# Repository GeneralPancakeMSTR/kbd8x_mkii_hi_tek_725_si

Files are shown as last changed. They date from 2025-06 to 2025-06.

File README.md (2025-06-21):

# KBD8XMKII "Space Invaders" TKL
PCB For NMB Hi-Tek Series 725 "Space Invaders" Switches and KBDFans KBD8XMKII TKL Keyboard. 

It's for this keyboard:


<center><p>My personal KBD8XMKII Keyboard</p></center>

Probably *literally* that keyboard, which is mine (I can only imagine the Venn diagram of Space Invaders collectors and KBD8XMKII owners is two distant circles). It's a [KBDFans](https://kbdfans.com/) KBD8XMKII, which isn't made anymore. I don't even think you can find it on their website, which seems to just [redirect you to their MKIII](https://kbdfans.com/collections/kbd8x-mkii-1) when you go looking for it. 

Anyway, the [KBD8XMKII](https://ai03.com/projects/kbd8x-mkii/) (scroll to the bottom for the PCB and plate files) was a keyboard designed by the renowned ai03, who graciously open-sourced the project, which helped make this one possible by derivation. Thanks! 

This PCB is specifically designed for use with [NMB Hi-Tek Series 725 "Space Invaders" switches](https://telcontar.net/KBK/Hi-Tek/Series_725) (this is the first link a search came up with), which also aren't made anymore. As you can see, this project has truly reached maximum usefulness. 

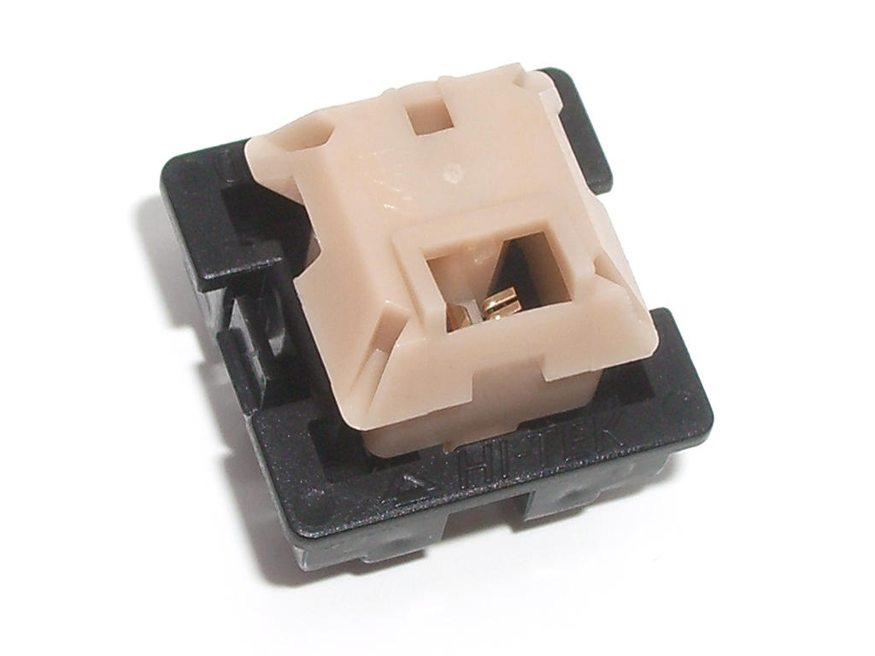
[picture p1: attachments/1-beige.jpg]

<center><p>A Beige (tactile) NMB Hi-Tek Series 725 "Space Invaders" Switch </p></center>

I've been a mechanical keyboard hobbyist for a while now (a decade?), and I've wanted to make my own keyboard about from the beginning. The hangup for me has always been the PCB, so instead of trying to make an expensive CNC case and (hopefully) figuring out the PCB later, I finally decided that to push that particular project forward I would learn the PCB side of things and then revisit the case aspect with some new knowledge and experience under my belt. 

## Reference Photos 
- PCB Top 
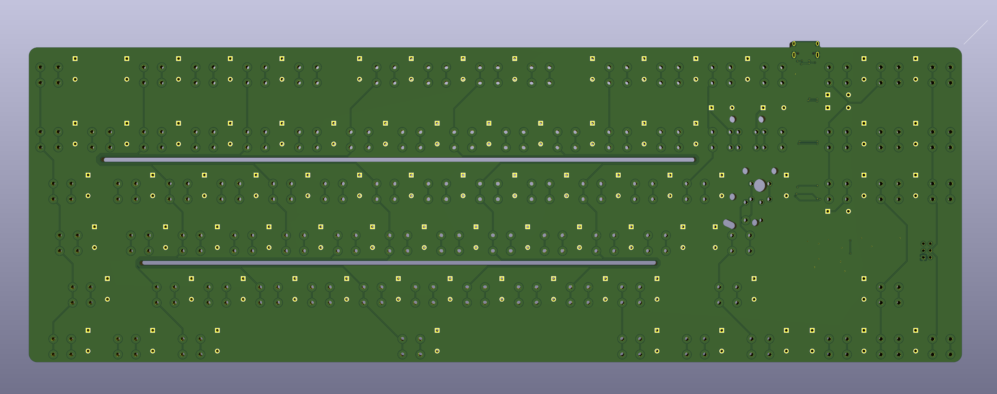
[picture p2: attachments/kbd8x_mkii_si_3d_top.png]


- PCB Bottom
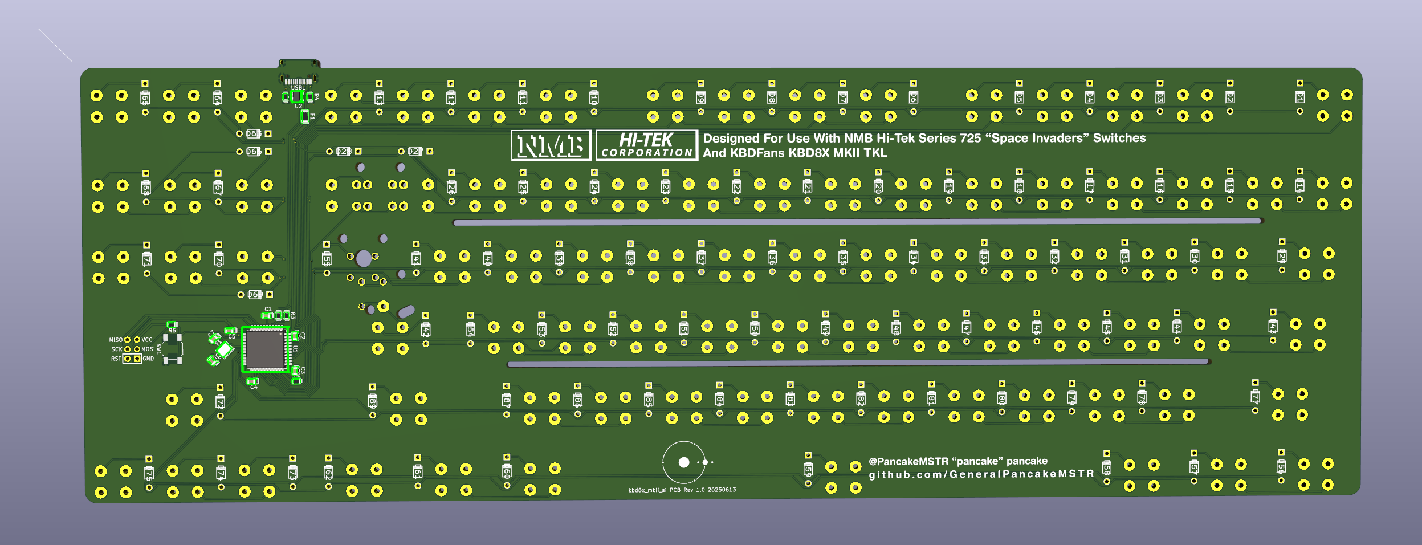
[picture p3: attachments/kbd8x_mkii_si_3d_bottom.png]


- Schematic (Logic)
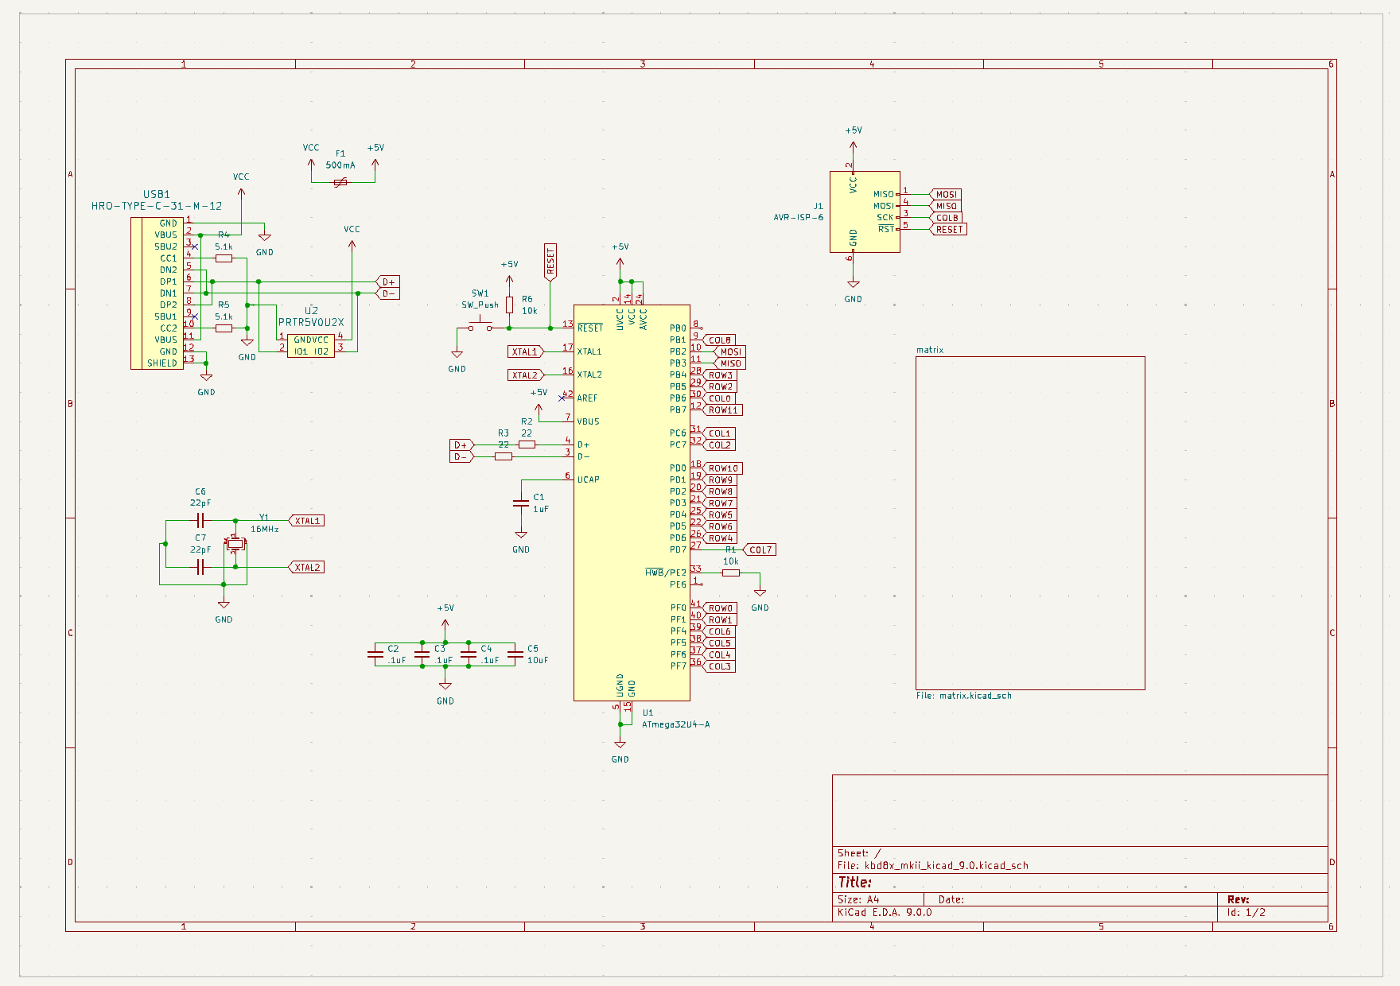
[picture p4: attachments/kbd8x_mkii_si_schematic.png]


- Schematic (Matrix)
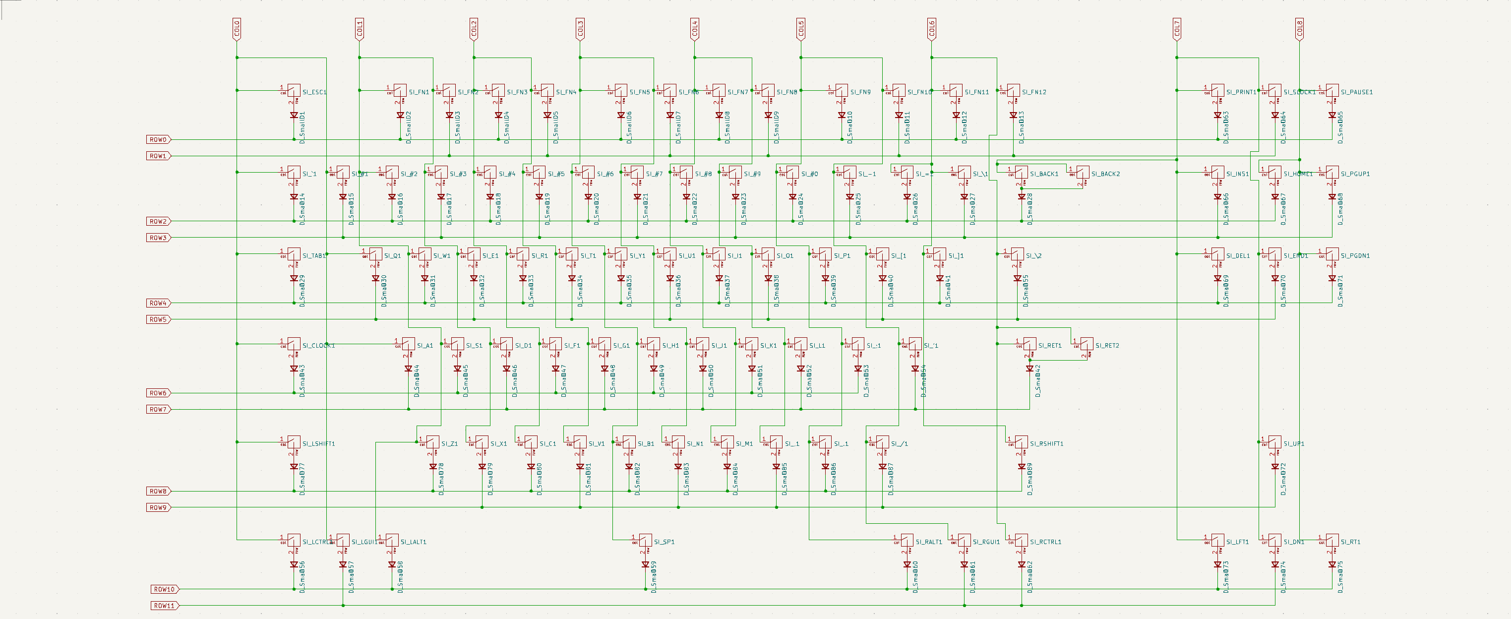
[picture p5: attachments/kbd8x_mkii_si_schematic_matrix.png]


- Layout/PCB 
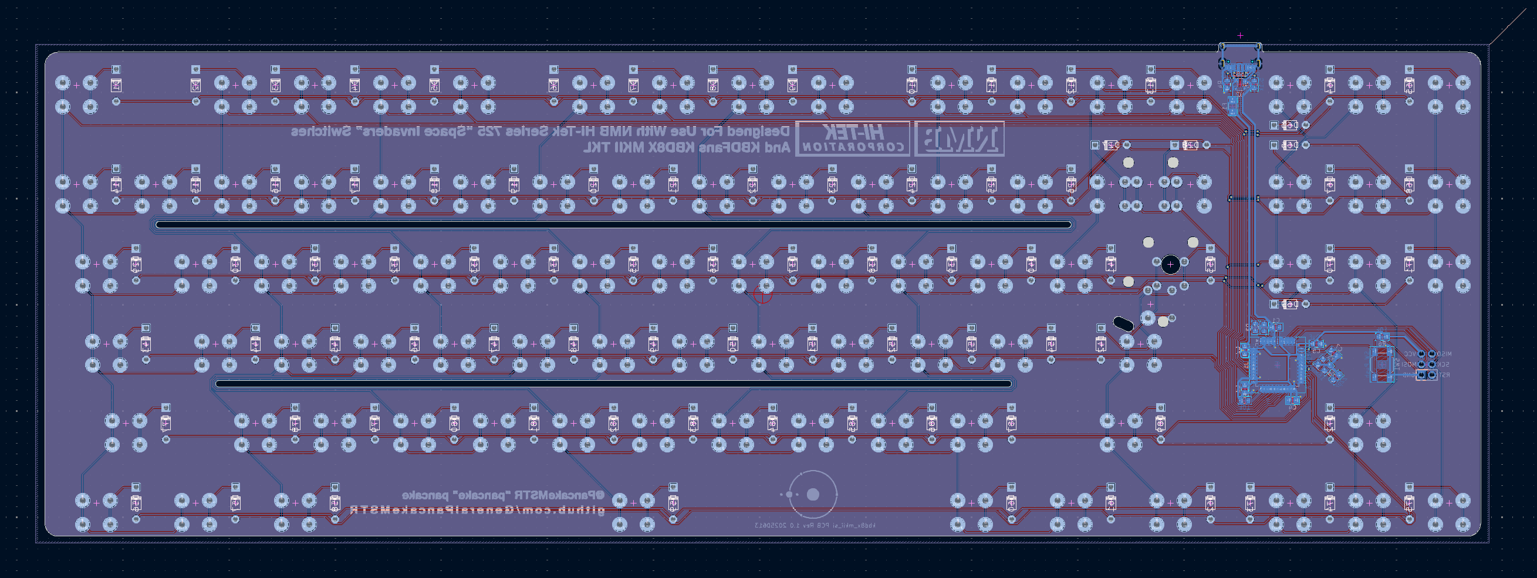
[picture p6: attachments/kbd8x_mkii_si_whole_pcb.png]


- Layout/PCB (MCU + USB)
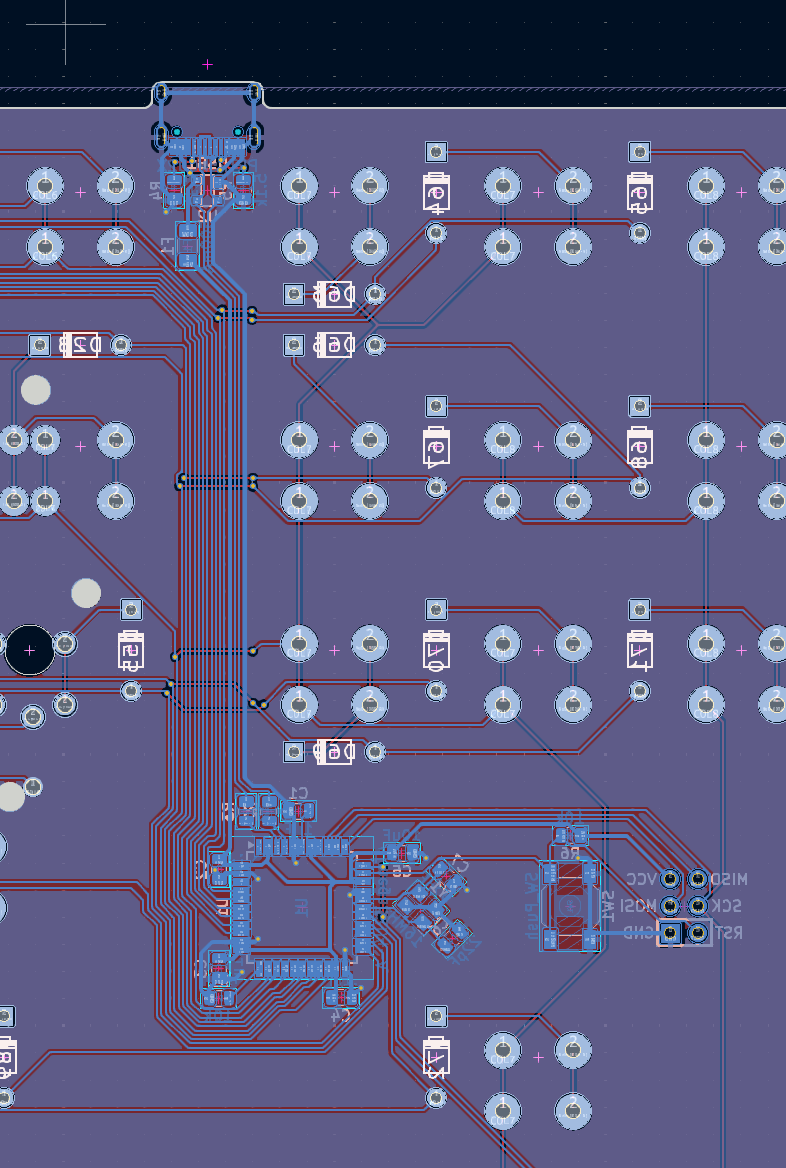
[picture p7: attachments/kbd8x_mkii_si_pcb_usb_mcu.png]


- Layout/PCB (USB)
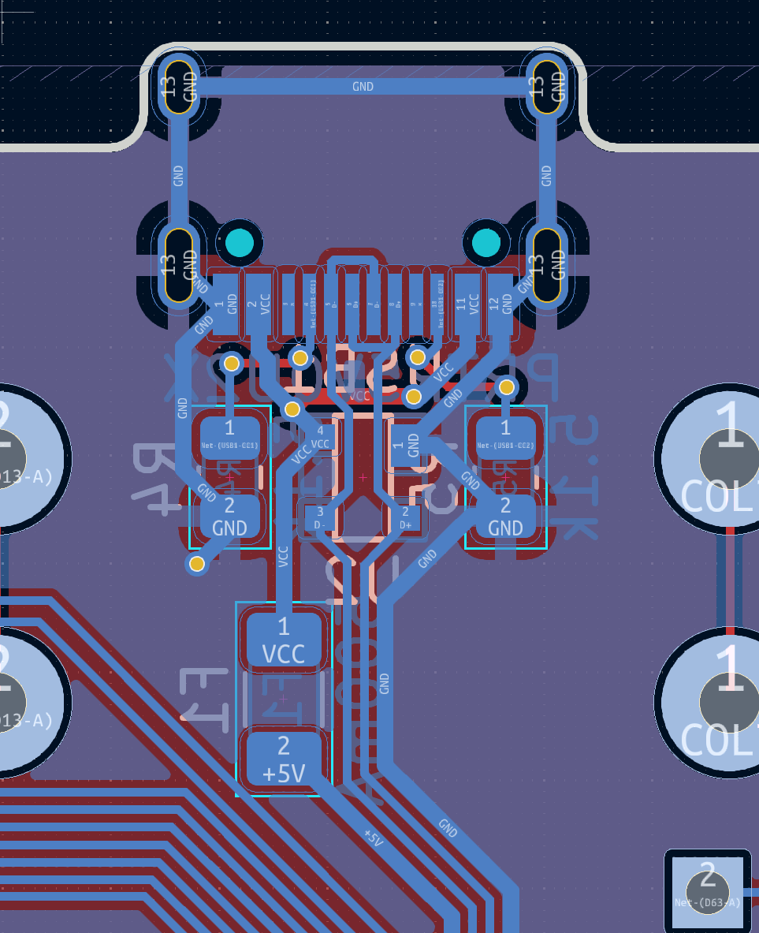
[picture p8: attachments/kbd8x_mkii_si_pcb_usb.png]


- Layout/PCB (MCU)
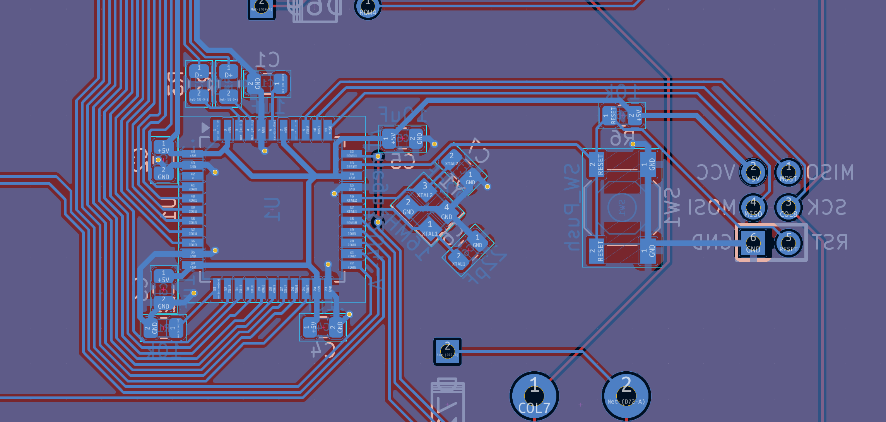
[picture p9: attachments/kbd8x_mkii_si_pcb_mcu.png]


## Notes 
- If shims are needed, these could be an option: [Clipped Washer 18-8 Stainless Steel, for M2 Screw Size, 2.200 mm ID, 4.500 mm OD](https://www.mcmaster.com/96025A268/)

- **IMPORTANT**: The placement of the Atmega32u4 in JLCPCB's PCBA may be wrong and need to be rotated. If you are getting this PCB made with PCBA, **quadruple check the placement of all of the components.**

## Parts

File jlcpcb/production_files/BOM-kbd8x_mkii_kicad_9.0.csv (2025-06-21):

Comment | Designator | Footprint | LCSC | Quantity
16MHz | Y1 | Crystal_SMD_3225-4Pin_3.2x2.5mm | C13738 | 1
10uF | C5 | C_0805_2012Metric | C15850 | 1
HRO-TYPE-C-31-M-12 | USB1 | HRO-TYPE-C-31-M-12 | C165948 | 1
10k | R1,R6 | R_0805_2012Metric | C17414 | 2
22 | R2,R3 | R_0805_2012Metric | C17561 | 2
22pF | C6,C7 | C_0805_2012Metric | C1804 | 2
ATmega32U4-A | U1 | TQFP-44_10x10mm_P0.8mm | C2052746 | 1
5.1k | R4,R5 | R_0805_2012Metric | C27834 | 2
1uF | C1 | C_0805_2012Metric | C28323 | 1

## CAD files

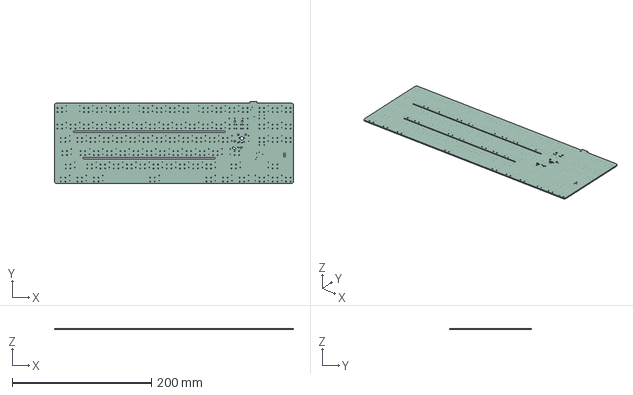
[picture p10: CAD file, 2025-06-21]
kbd8x_mkii_kicad_9.0.step
343.7 x 118.3 x 1.51 mm

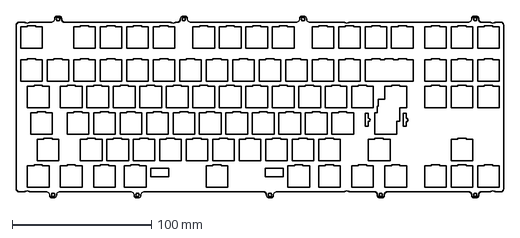
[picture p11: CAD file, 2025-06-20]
kbd8x_mkii_hi_tek_725_si_plate.dxf
350.6 x 130.7 mm

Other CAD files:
models/kbd8x_mkii_adjusted_origin.step
models/kbd8x_mkii_kicad_9.0.step

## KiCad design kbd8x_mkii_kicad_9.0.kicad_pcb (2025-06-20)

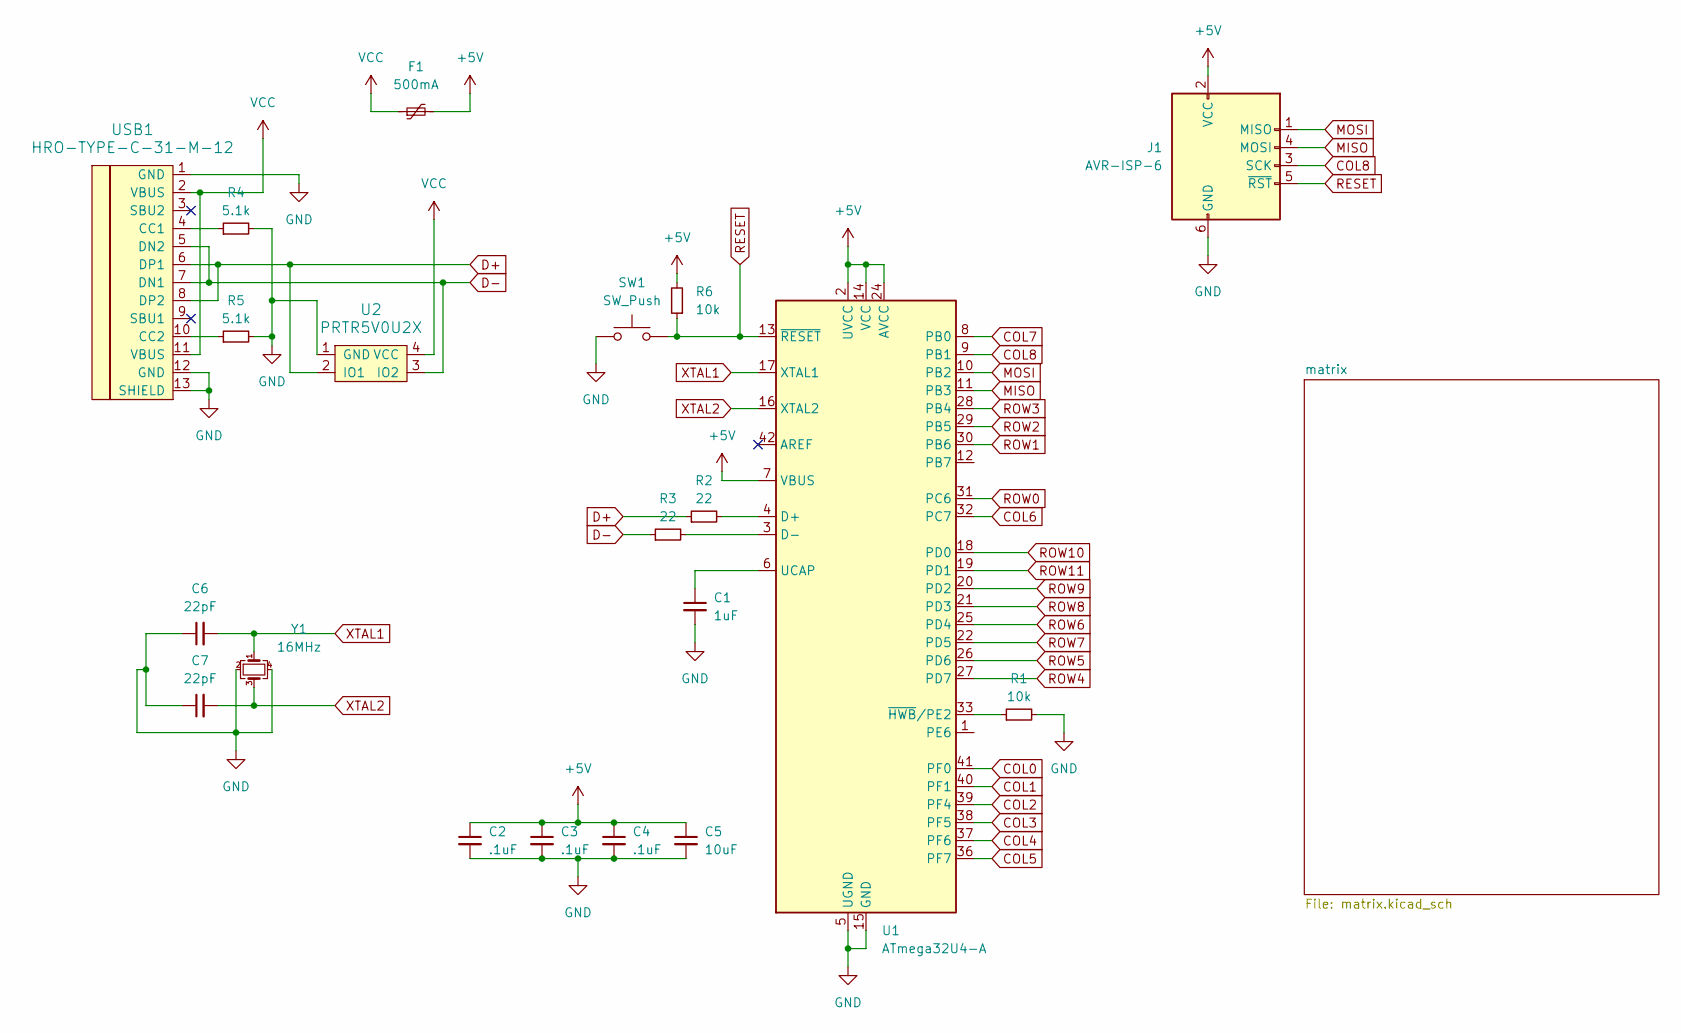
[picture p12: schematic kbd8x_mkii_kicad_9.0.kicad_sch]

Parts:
C1: 1uF; C_0805_2012Metric
C2, C3, C4: .1uF; C_0805_2012Metric
C5: 10uF; C_0805_2012Metric
C6, C7: 22pF; C_0805_2012Metric
F1: 500mA; Fuse_1206_3216Metric
J1: AVR-ISP-6; Reset_Pretty-Mask
R1, R6: 10k; R_0805_2012Metric
R2, R3: 22; R_0805_2012Metric
R4, R5: 5.1k; R_0805_2012Metric
SW1: SW_Push; SW_SPST_SKQG_WithStem
U1: ATmega32U4-A; TQFP-44_10x10mm_P0.8mm
U2: PRTR5V0U2X; SOT143B
USB1: HRO-TYPE-C-31-M-12
Y1: 16MHz; Crystal_SMD_3225-4Pin_3.2x2.5mm

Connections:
+5V: C2.1, C3.1, C4.1, C5.1, F1.2, J1.2 (VCC), R6.2, U1.2 (UVCC), U1.7 (VBUS), U1.14 (VCC), U1.24 (AVCC), U1.34 (VCC), U1.44 (AVCC)
COL0: U1.41 (PF0); also elsewhere on the board
COL1: U1.40 (PF1); also elsewhere on the board
COL2: U1.39 (PF4); also elsewhere on the board
COL3: U1.38 (PF5); also elsewhere on the board
COL4: U1.37 (PF6); also elsewhere on the board
COL5: U1.36 (PF7); also elsewhere on the board
COL6: U1.32 (PC7); also elsewhere on the board
COL7: U1.8 (PB0); also elsewhere on the board
COL8: J1.3 (SCK), U1.9 (PB1); also elsewhere on the board
D+: R2.1, U2.2 (IO1), USB1.6 (DP1), USB1.8 (DP2)
D-: R3.1, U2.3 (IO2), USB1.5 (DN2), USB1.7 (DN1)
GND: C1.2, C2.2, C3.2, C4.2, C5.2, C6.1, C7.1, J1.6 (GND), R1.2, R4.2, R5.2, SW1.1, U1.5 (UGND), U1.15 (GND), U1.23 (GND), U1.35 (GND), U1.43 (GND), U2.1 (GND), USB1.1 (GND), USB1.12 (GND), USB1.13 (SHIELD), Y1.2, Y1.4
MISO: J1.4 (MOSI), U1.11 (PB3)
MOSI: J1.1 (MISO), U1.10 (PB2)
unnamed: R2.2, U1.4 (D+)
unnamed: R3.2, U1.3 (D-)
unnamed: C1.1, U1.6 (UCAP)
unnamed: R1.1, U1.33 (~HWB/PE2)
unnamed: R4.1, USB1.4 (CC1)
unnamed: R5.1, USB1.10 (CC2)
RESET: J1.5 (~RST), R6.1, SW1.2, U1.13 (~RESET)
ROW0: U1.31 (PC6); also elsewhere on the board
ROW1: U1.30 (PB6); also elsewhere on the board
ROW2: U1.29 (PB5); also elsewhere on the board
ROW3: U1.28 (PB4); also elsewhere on the board
ROW4: U1.27 (PD7); also elsewhere on the board
ROW5: U1.26 (PD6); also elsewhere on the board
ROW6: U1.25 (PD4); also elsewhere on the board
ROW7: U1.22 (PD5); also elsewhere on the board
ROW8: U1.21 (PD3); also elsewhere on the board
ROW9: U1.20 (PD2); also elsewhere on the board
ROW10: U1.18 (PD0); also elsewhere on the board
ROW11: U1.19 (PD1); also elsewhere on the board
VCC: F1.1, U2.4 (VCC), USB1.2 (VBUS), USB1.11 (VBUS)
XTAL1: C6.2, U1.17 (XTAL1), Y1.1
XTAL2: C7.2, U1.16 (XTAL2), Y1.3

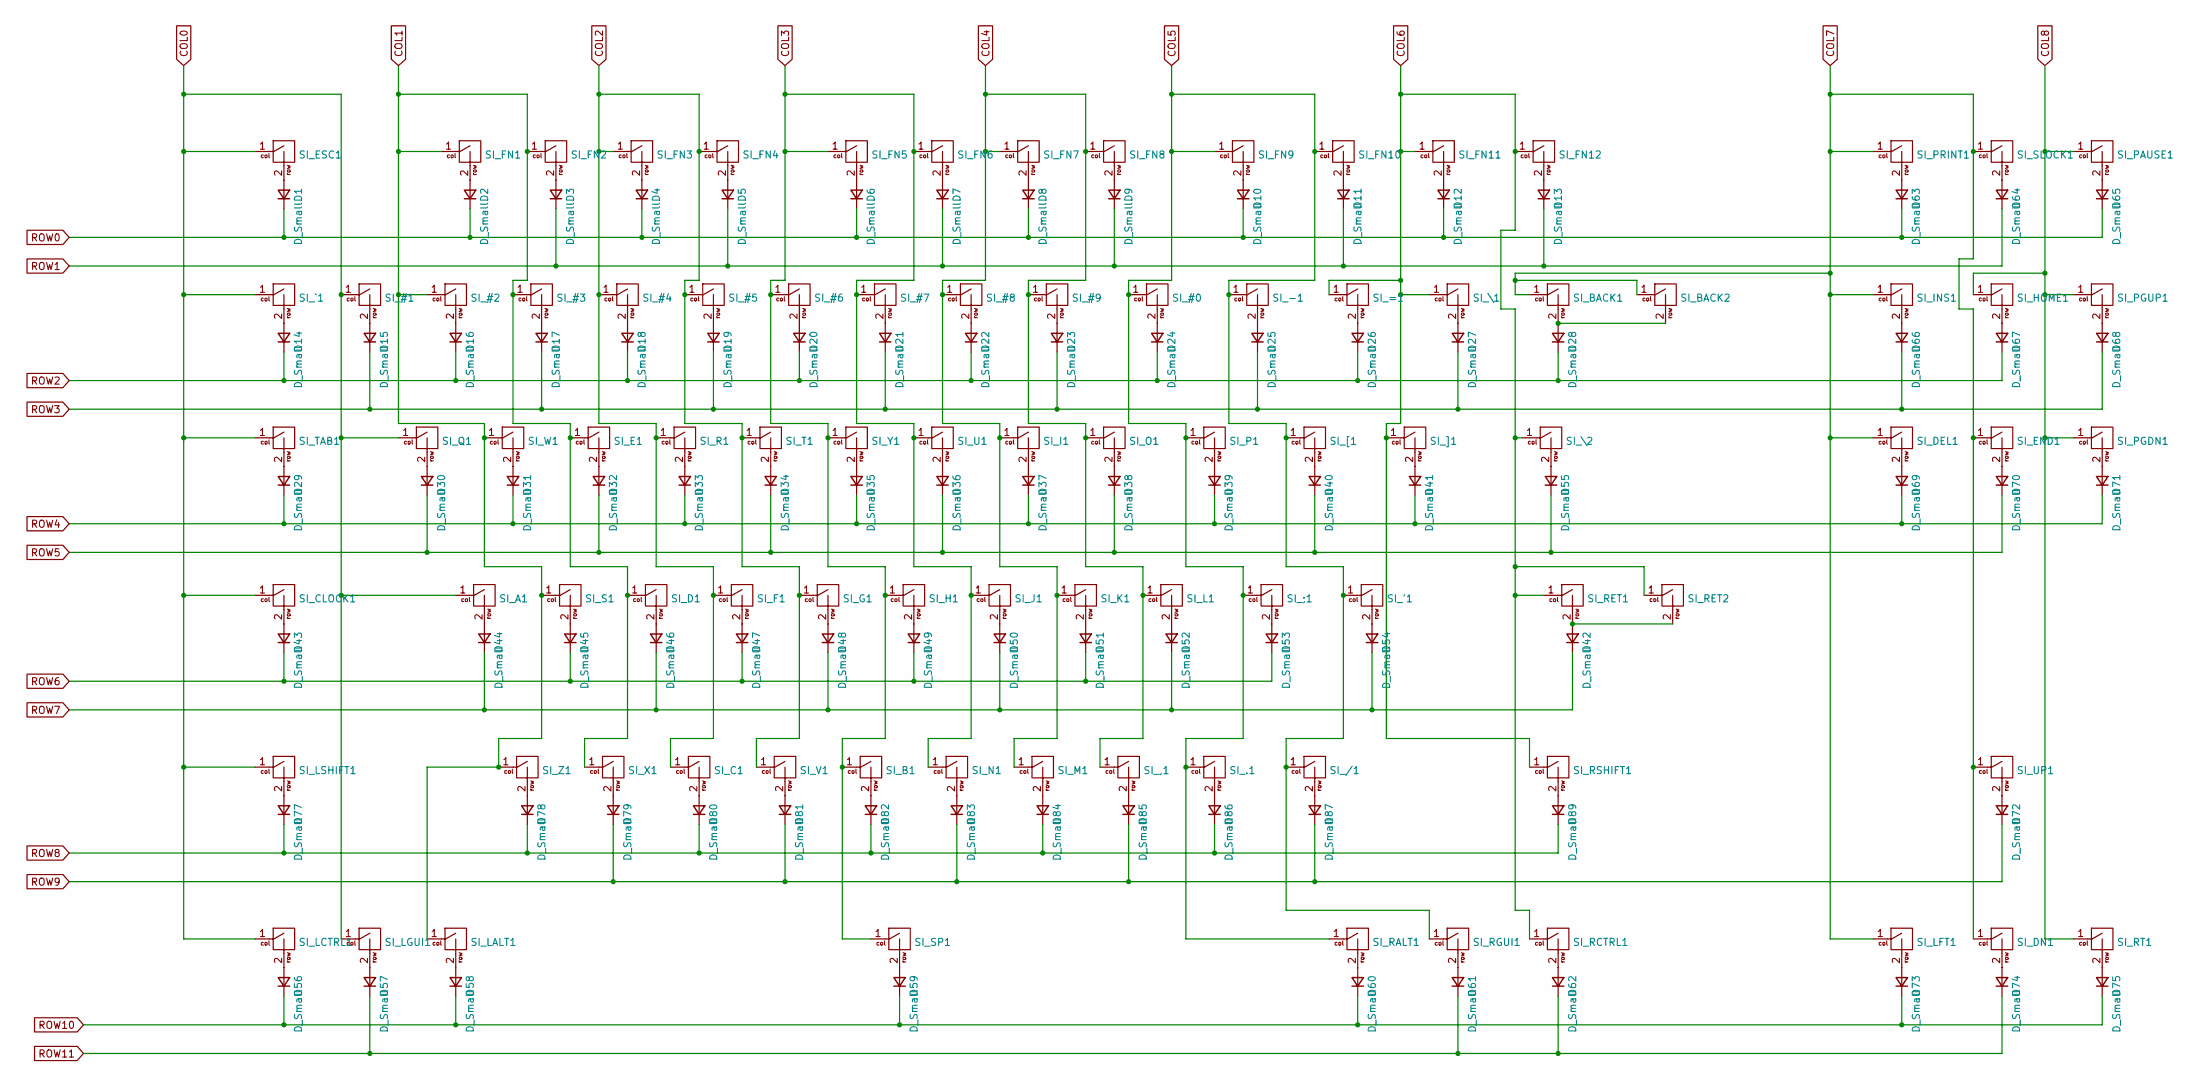
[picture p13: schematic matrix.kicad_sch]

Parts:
D1, D2, D3, D4, D5, D6, D7, D8, D9, D10, D11, D12, D13, D14, D15, D16, D17, D18, D19, D20, D21, D22, D23, D24, D25, D26, D27, D28, D29, D30, D31, D32, D33, D34, D35, D36, D37, D38, D39, D40, D41, D42, D43, D44, D45, D46, D47, D48, D49, D50, D51, D52, D53, D54, D55, D56, D57, D58, D59, D60, D61, D62, D63, D64, D65, D66, D67, D68, D69, D70, D71, D72, D73, D74, D75, D77, D78, D79, D80, D81, D82, D83, D84, D85, D86, D87, D89: D_Small; Diode
SI_#0, SI_#1, SI_#2, SI_#3, SI_#4, SI_#5, SI_#6, SI_#7, SI_#8, SI_#9: Hitek725-1U
SI_'1: Hitek725-1U
SI_,1: Hitek725-1U
SI_-1: Hitek725-1U
SI_.1: Hitek725-1U
SI_/1: Hitek725-1U
SI_;1: Hitek725-1U
SI_=1: Hitek725-1U
SI_A1: Hitek725-1U
SI_B1: Hitek725-1U
SI_BACK1, SI_BACK2: Hitek725-1U
SI_C1: Hitek725-1U
SI_CLOCK1: Hitek725-1.75U
SI_D1: Hitek725-1U
SI_DEL1: Hitek725-1U
SI_DN1: Hitek725-1U
SI_E1: Hitek725-1U
SI_END1: Hitek725-1U
SI_ESC1: Hitek725-1U
SI_F1: Hitek725-1U
SI_FN1, SI_FN2, SI_FN3, SI_FN4, SI_FN5, SI_FN6, SI_FN7, SI_FN8, SI_FN9, SI_FN10, SI_FN11, SI_FN12: Hitek725-1U
SI_G1: Hitek725-1U
SI_H1: Hitek725-1U
SI_HOME1: Hitek725-1U
SI_I1: Hitek725-1U
SI_INS1: Hitek725-1U
SI_J1: Hitek725-1U
SI_K1: Hitek725-1U
SI_L1: Hitek725-1U
SI_LALT1: Hitek725-1.5U
SI_LCTRL1: Hitek725-1.5U
SI_LFT1: Hitek725-1U
SI_LGUI1: Hitek725-1U
SI_LSHIFT1: Hitek725-2.25U
SI_M1: Hitek725-1U
SI_N1: Hitek725-1U
SI_O1: Hitek725-1U
SI_P1: Hitek725-1U
SI_PAUSE1: Hitek725-1U
SI_PGDN1: Hitek725-1U
SI_PGUP1: Hitek725-1U
SI_PRINT1: Hitek725-1U
SI_Q1: Hitek725-1U
SI_R1: Hitek725-1U
SI_RALT1: Hitek725-1.5U
SI_RCTRL1: Hitek725-1.5U
SI_RET1: Hitek725-BigAssEnter
SI_RET2: Hitek725-2.25U
SI_RGUI1: Hitek725-1U
SI_RSHIFT1: Hitek725-2.75U
SI_RT1: Hitek725-1U
SI_S1: Hitek725-1U
SI_SLOCK1: Hitek725-1U
SI_SP1: Hitek725-7U
SI_T1: Hitek725-1U
SI_TAB1: Hitek725-1.5U
SI_U1: Hitek725-1U
SI_UP1: Hitek725-1U
SI_V1: Hitek725-1U
SI_W1: Hitek725-1U
SI_X1: Hitek725-1U
SI_Y1: Hitek725-1U
SI_Z1: Hitek725-1U
SI_[1: Hitek725-1U
SI_\1, SI_\2: Hitek725-1U
SI_]1: Hitek725-1U
SI_`1: Hitek725-1U

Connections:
COL0: SI_#1.1, SI_A1.1, SI_CLOCK1.1, SI_ESC1.1, SI_LCTRL1.1, SI_LGUI1.1, SI_LSHIFT1.1, SI_Q1.1, SI_TAB1.1, SI_`1.1; also elsewhere on the board
COL1: SI_#2.1, SI_#3.1, SI_D1.1, SI_E1.1, SI_FN1.1, SI_FN2.1, SI_LALT1.1, SI_S1.1, SI_W1.1, SI_X1.1, SI_Z1.1; also elsewhere on the board
COL2: SI_#4.1, SI_#5.1, SI_C1.1, SI_F1.1, SI_FN3.1, SI_FN4.1, SI_G1.1, SI_R1.1, SI_T1.1, SI_V1.1; also elsewhere on the board
COL3: SI_#6.1, SI_#7.1, SI_B1.1, SI_FN5.1, SI_FN6.1, SI_H1.1, SI_J1.1, SI_N1.1, SI_SP1.1, SI_U1.1, SI_Y1.1; also elsewhere on the board
COL4: SI_#8.1, SI_#9.1, SI_,1.1, SI_FN7.1, SI_FN8.1, SI_I1.1, SI_K1.1, SI_L1.1, SI_M1.1, SI_O1.1; also elsewhere on the board
COL5: SI_#0.1, SI_'1.1, SI_-1.1, SI_.1.1, SI_/1.1, SI_;1.1, SI_FN9.1, SI_FN10.1, SI_P1.1, SI_RALT1.1, SI_RGUI1.1, SI_[1.1; also elsewhere on the board
COL6: SI_=1.1, SI_FN11.1, SI_FN12.1, SI_RCTRL1.1, SI_RET1.1, SI_RET2.1, SI_RSHIFT1.1, SI_\1.1, SI_\2.1, SI_]1.1; also elsewhere on the board
COL7: SI_BACK1.1, SI_BACK2.1, SI_DEL1.1, SI_DN1.1, SI_END1.1, SI_INS1.1, SI_LFT1.1, SI_PRINT1.1, SI_SLOCK1.1, SI_UP1.1; also elsewhere on the board
COL8: SI_HOME1.1, SI_PAUSE1.1, SI_PGDN1.1, SI_PGUP1.1, SI_RT1.1; also elsewhere on the board
unnamed: D1.2 (A), SI_ESC1.2
unnamed: D2.2 (A), SI_FN1.2
unnamed: D3.2 (A), SI_FN2.2
unnamed: D4.2 (A), SI_FN3.2
unnamed: D5.2 (A), SI_FN4.2
unnamed: D6.2 (A), SI_FN5.2
unnamed: D7.2 (A), SI_FN6.2
unnamed: D8.2 (A), SI_FN7.2
unnamed: D9.2 (A), SI_FN8.2
unnamed: D10.2 (A), SI_FN9.2
unnamed: D11.2 (A), SI_FN10.2
unnamed: D12.2 (A), SI_FN11.2
unnamed: D13.2 (A), SI_FN12.2
unnamed: D14.2 (A), SI_`1.2
unnamed: D15.2 (A), SI_#1.2
unnamed: D16.2 (A), SI_#2.2
unnamed: D17.2 (A), SI_#3.2
unnamed: D18.2 (A), SI_#4.2
unnamed: D19.2 (A), SI_#5.2
unnamed: D20.2 (A), SI_#6.2
unnamed: D21.2 (A), SI_#7.2
unnamed: D22.2 (A), SI_#8.2
unnamed: D23.2 (A), SI_#9.2
unnamed: D24.2 (A), SI_#0.2
unnamed: D25.2 (A), SI_-1.2
unnamed: D26.2 (A), SI_=1.2
unnamed: D27.2 (A), SI_\1.2
unnamed: D28.2 (A), SI_BACK1.2, SI_BACK2.2
unnamed: D29.2 (A), SI_TAB1.2
unnamed: D30.2 (A), SI_Q1.2
unnamed: D31.2 (A), SI_W1.2
unnamed: D32.2 (A), SI_E1.2
unnamed: D33.2 (A), SI_R1.2
unnamed: D34.2 (A), SI_T1.2
unnamed: D35.2 (A), SI_Y1.2
unnamed: D36.2 (A), SI_U1.2
unnamed: D37.2 (A), SI_I1.2
unnamed: D38.2 (A), SI_O1.2
unnamed: D39.2 (A), SI_P1.2
unnamed: D40.2 (A), SI_[1.2
unnamed: D41.2 (A), SI_]1.2
unnamed: D42.2 (A), SI_RET1.2, SI_RET2.2
unnamed: D43.2 (A), SI_CLOCK1.2
unnamed: D44.2 (A), SI_A1.2
unnamed: D45.2 (A), SI_S1.2
unnamed: D46.2 (A), SI_D1.2
unnamed: D47.2 (A), SI_F1.2
unnamed: D48.2 (A), SI_G1.2
unnamed: D49.2 (A), SI_H1.2
unnamed: D50.2 (A), SI_J1.2
unnamed: D51.2 (A), SI_K1.2
unnamed: D52.2 (A), SI_L1.2
unnamed: D53.2 (A), SI_;1.2
unnamed: D54.2 (A), SI_'1.2
unnamed: D55.2 (A), SI_\2.2
unnamed: D56.2 (A), SI_LCTRL1.2
unnamed: D57.2 (A), SI_LGUI1.2
unnamed: D58.2 (A), SI_LALT1.2
unnamed: D59.2 (A), SI_SP1.2
unnamed: D60.2 (A), SI_RALT1.2
unnamed: D61.2 (A), SI_RGUI1.2
unnamed: D62.2 (A), SI_RCTRL1.2
unnamed: D63.2 (A), SI_PRINT1.2
unnamed: D64.2 (A), SI_SLOCK1.2
unnamed: D65.2 (A), SI_PAUSE1.2
unnamed: D66.2 (A), SI_INS1.2
unnamed: D67.2 (A), SI_HOME1.2
unnamed: D68.2 (A), SI_PGUP1.2
unnamed: D69.2 (A), SI_DEL1.2
unnamed: D70.2 (A), SI_END1.2
unnamed: D71.2 (A), SI_PGDN1.2
unnamed: D72.2 (A), SI_UP1.2
unnamed: D73.2 (A), SI_LFT1.2
unnamed: D74.2 (A), SI_DN1.2
unnamed: D75.2 (A), SI_RT1.2
unnamed: D77.2 (A), SI_LSHIFT1.2
unnamed: D78.2 (A), SI_Z1.2
unnamed: D79.2 (A), SI_X1.2
unnamed: D80.2 (A), SI_C1.2
unnamed: D81.2 (A), SI_V1.2
unnamed: D82.2 (A), SI_B1.2
unnamed: D83.2 (A), SI_N1.2
unnamed: D84.2 (A), SI_M1.2
unnamed: D85.2 (A), SI_,1.2
unnamed: D86.2 (A), SI_.1.2
unnamed: D87.2 (A), SI_/1.2
unnamed: D89.2 (A), SI_RSHIFT1.2
ROW0: D1.1 (K), D2.1 (K), D4.1 (K), D6.1 (K), D8.1 (K), D10.1 (K), D12.1 (K), D63.1 (K), D65.1 (K); also elsewhere on the board
ROW1: D3.1 (K), D5.1 (K), D7.1 (K), D9.1 (K), D11.1 (K), D13.1 (K), D64.1 (K); also elsewhere on the board
ROW2: D14.1 (K), D16.1 (K), D18.1 (K), D20.1 (K), D22.1 (K), D24.1 (K), D26.1 (K), D28.1 (K), D67.1 (K); also elsewhere on the board
ROW3: D15.1 (K), D17.1 (K), D19.1 (K), D21.1 (K), D23.1 (K), D25.1 (K), D27.1 (K), D66.1 (K), D68.1 (K); also elsewhere on the board
ROW4: D29.1 (K), D31.1 (K), D33.1 (K), D35.1 (K), D37.1 (K), D39.1 (K), D41.1 (K), D69.1 (K), D71.1 (K); also elsewhere on the board
ROW5: D30.1 (K), D32.1 (K), D34.1 (K), D36.1 (K), D38.1 (K), D40.1 (K), D55.1 (K), D70.1 (K); also elsewhere on the board
ROW6: D43.1 (K), D45.1 (K), D47.1 (K), D49.1 (K), D51.1 (K), D53.1 (K); also elsewhere on the board
ROW7: D42.1 (K), D44.1 (K), D46.1 (K), D48.1 (K), D50.1 (K), D52.1 (K), D54.1 (K); also elsewhere on the board
ROW8: D77.1 (K), D78.1 (K), D80.1 (K), D82.1 (K), D84.1 (K), D86.1 (K), D89.1 (K); also elsewhere on the board
ROW9: D72.1 (K), D79.1 (K), D81.1 (K), D83.1 (K), D85.1 (K), D87.1 (K); also elsewhere on the board
ROW10: D56.1 (K), D58.1 (K), D59.1 (K), D60.1 (K), D73.1 (K), D75.1 (K); also elsewhere on the board
ROW11: D57.1 (K), D61.1 (K), D62.1 (K), D74.1 (K); also elsewhere on the board

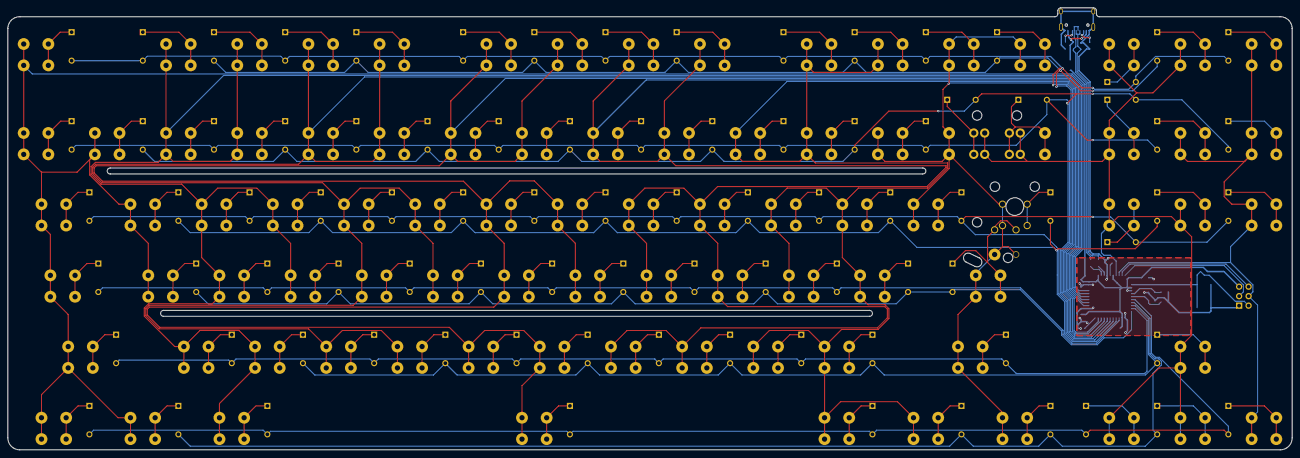
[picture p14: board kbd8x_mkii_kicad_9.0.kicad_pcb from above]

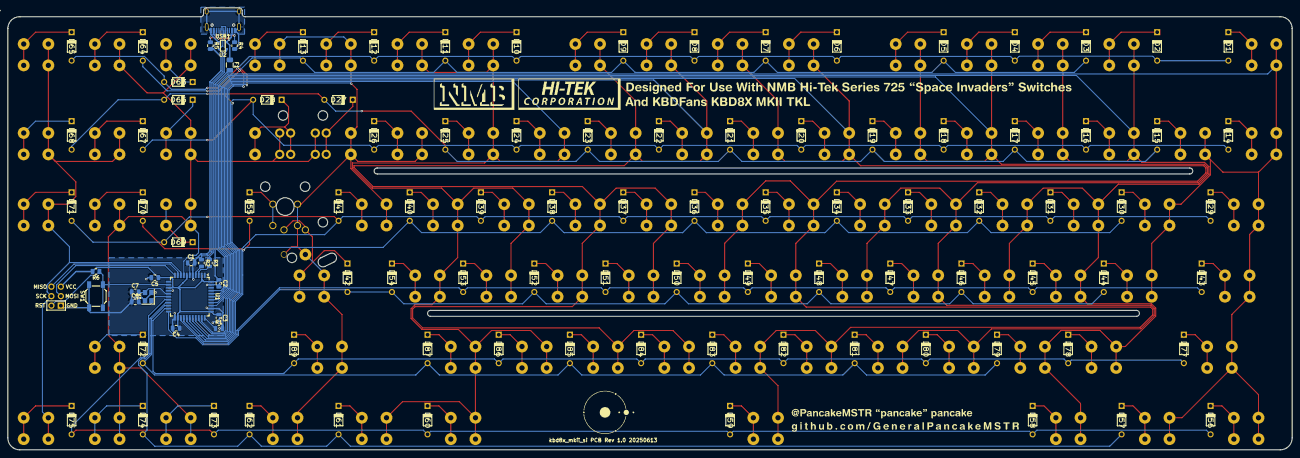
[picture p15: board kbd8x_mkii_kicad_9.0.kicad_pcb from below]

Board: 2 copper layers, 343.7 x 118.3 mm, 196 parts (107 on the bottom side), 124 nets.

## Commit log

2025-06-14 Initial Commit.
    [kbd8x_mkii_adjusted_origin.step, kbd8x_mkii_kicad_9.0.kicad_pcb, kbd8x_mkii_kicad_9.0.kicad_sch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]
2025-06-15 Light discussion and reference photos (README).
    [kbd8x_mkii_kicad_9.0.kicad_pcb]
2025-06-20 Revisions to make workable PCB and push before experimenting with some row and column adjustment to attempt to clean up traces.
    [kbd8x_mkii_hi_tek_725_si_plate.dxf, kbd8x_mkii_kicad_9.0.kicad_pcb]
2025-06-21 Applied row/col on different layers rule to clean up traces, hopefully ready for production.
    [kbd8x_mkii_kicad_9.0.kicad_sch]
2025-06-21 Production (Rev 1.0 20250613).
    [BOM-kbd8x_mkii_kicad_9.0.csv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]
